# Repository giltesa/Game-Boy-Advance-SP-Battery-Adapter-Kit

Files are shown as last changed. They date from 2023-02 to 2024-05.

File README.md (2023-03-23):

# Game Boy Advance SP Battery Adapter Kit

Once your **Game Boy Advance SP battery** has gone bad, and you start to look for a replacement you will see it is impossible to find original batteries since they expire if you do not keep charged with a minimum level of charge.

Compatible batteries may be an alternative. However, some manufacturers  may lie with the real capacity or their quality is not good enough.

If you have changed the screen for a IPS screen, or the [charging port for a USB-C port](https://shop.giltesa.com/product/game-boy-advance-sp-usb-c-kit-centered/ "charging port for a USB-C port"). I am sure you will also want to replace the battery and make your GBA SP perfect. This kit helps you to install any li-ion battery, however the best option is the [603048](https://www.aliexpress.com/item/4001084877373.html? "603048") which has 900mAh, that is 300mAh more than the original!

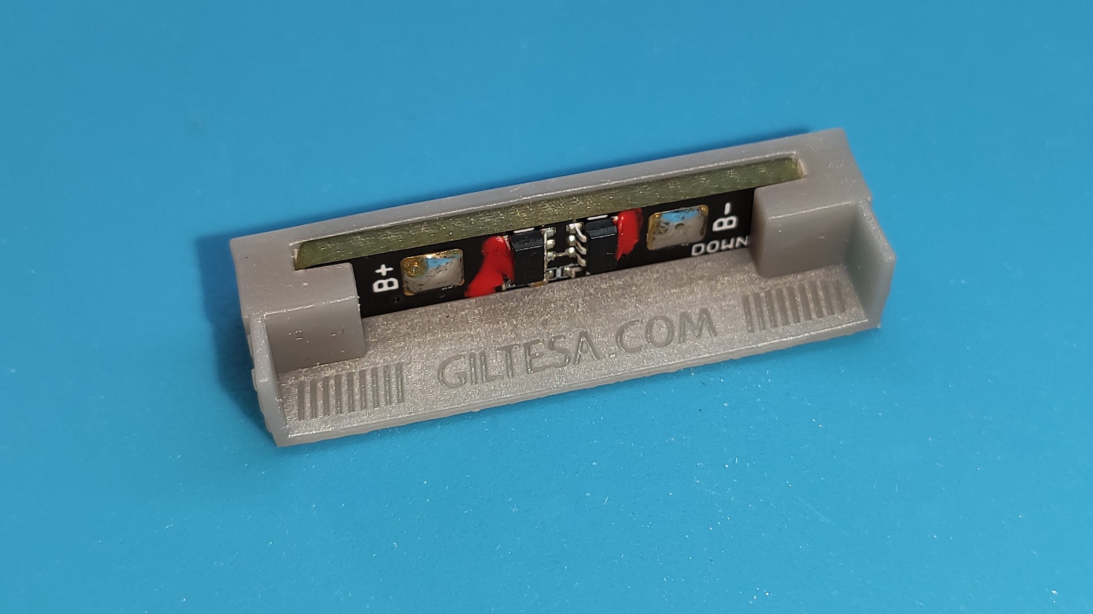
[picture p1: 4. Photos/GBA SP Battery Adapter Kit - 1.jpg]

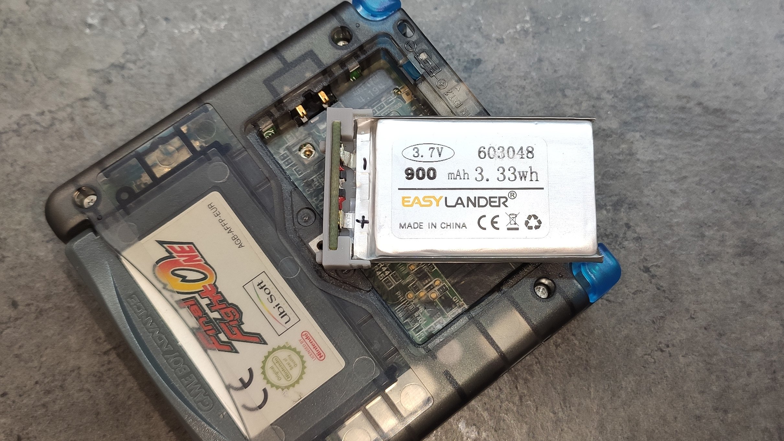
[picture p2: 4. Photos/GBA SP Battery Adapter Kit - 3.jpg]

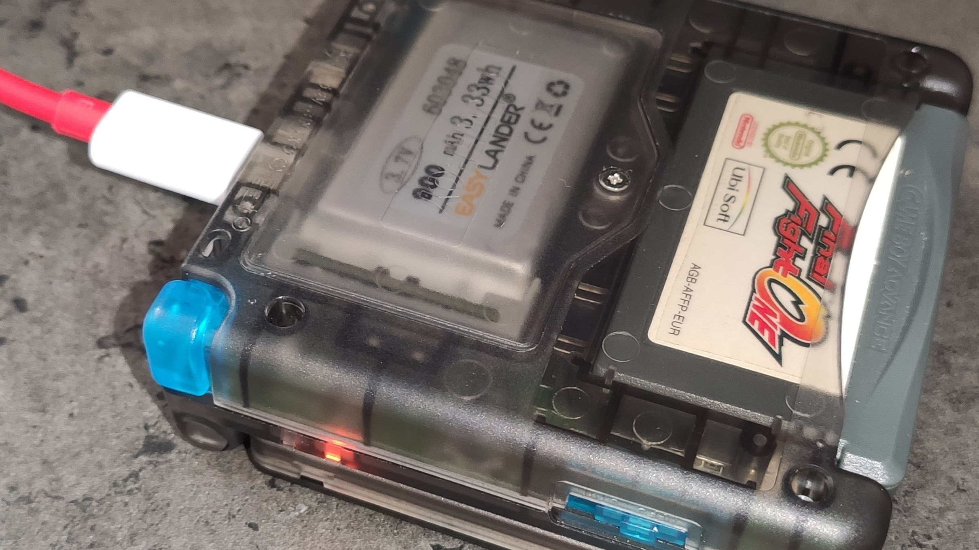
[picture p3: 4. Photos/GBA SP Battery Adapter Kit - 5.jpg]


## Would you like it?

https://shop.giltesa.com/product/game-boy-advance-sp-battery-adapter-kit

## More

- [giltesa.com](https://giltesa.com "giltesa.com")
- [twitter.com](https://twitter.com/giltesa/status/1503669454852481024 "twitter.com")

## License

This project is licensed under a **Creative Commons** license:
**[Attribution-NonCommercial-ShareAlike 4.0 International (CC BY-NC-SA 4.0) ](https://creativecommons.org/licenses/by-nc-sa/4.0/)**

Check the [LICENSE.md](LICENSE.md) for more information.

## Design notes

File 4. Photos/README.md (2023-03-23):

GBASP-BAT
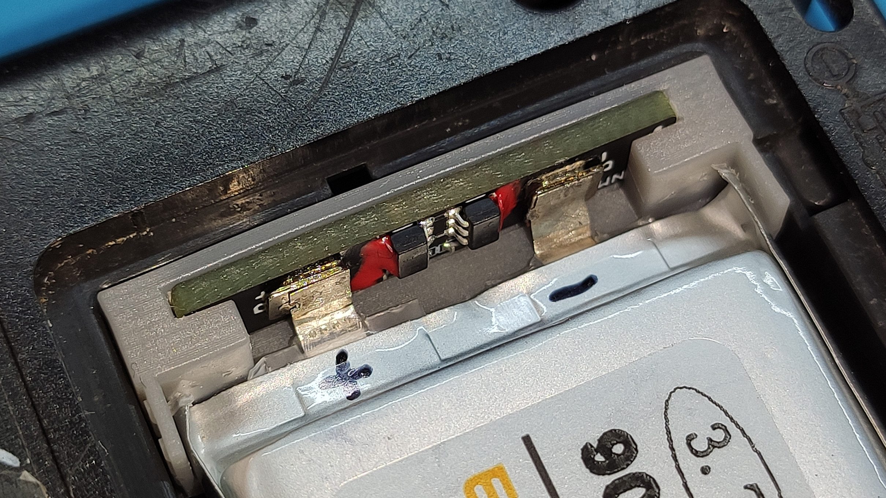
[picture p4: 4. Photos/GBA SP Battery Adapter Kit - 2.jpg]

GBASP-BAT
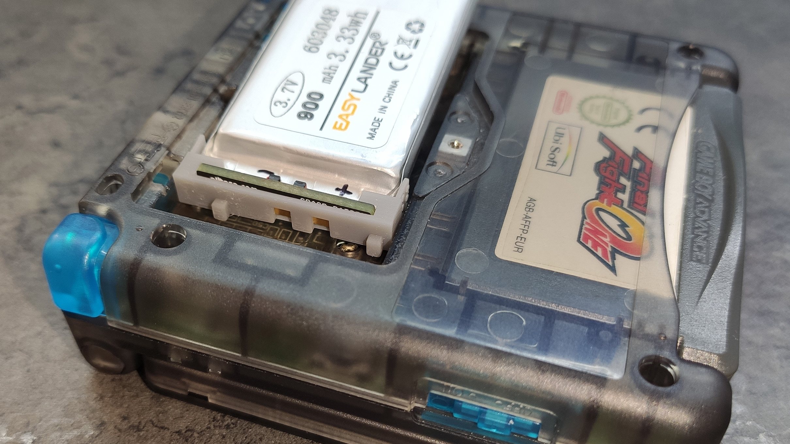
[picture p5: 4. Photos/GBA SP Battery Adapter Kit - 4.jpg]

GBASP-BAT
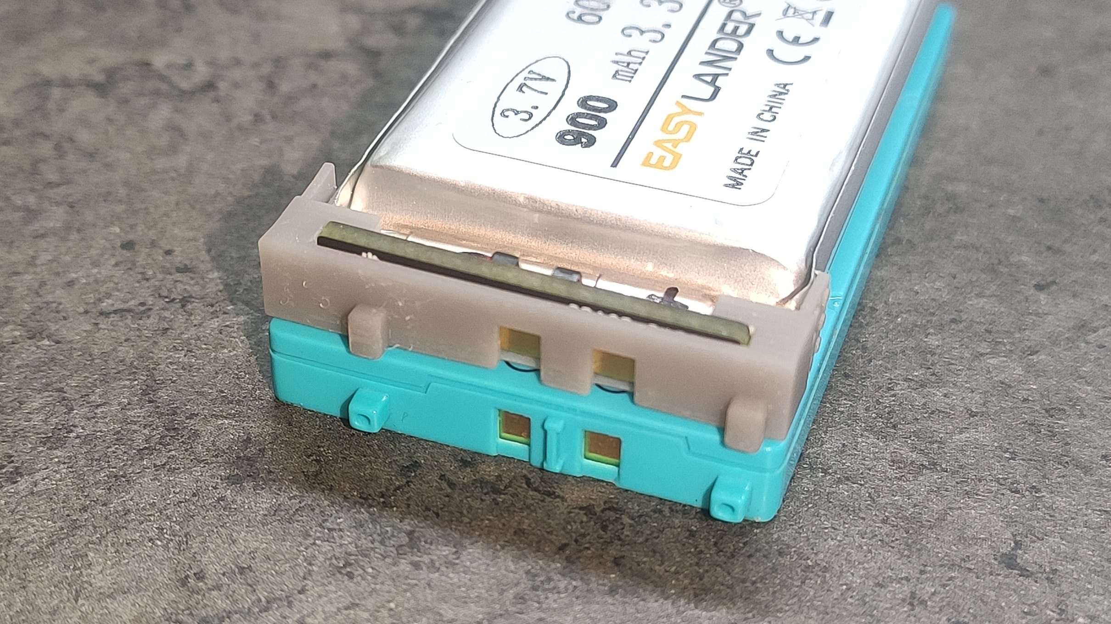
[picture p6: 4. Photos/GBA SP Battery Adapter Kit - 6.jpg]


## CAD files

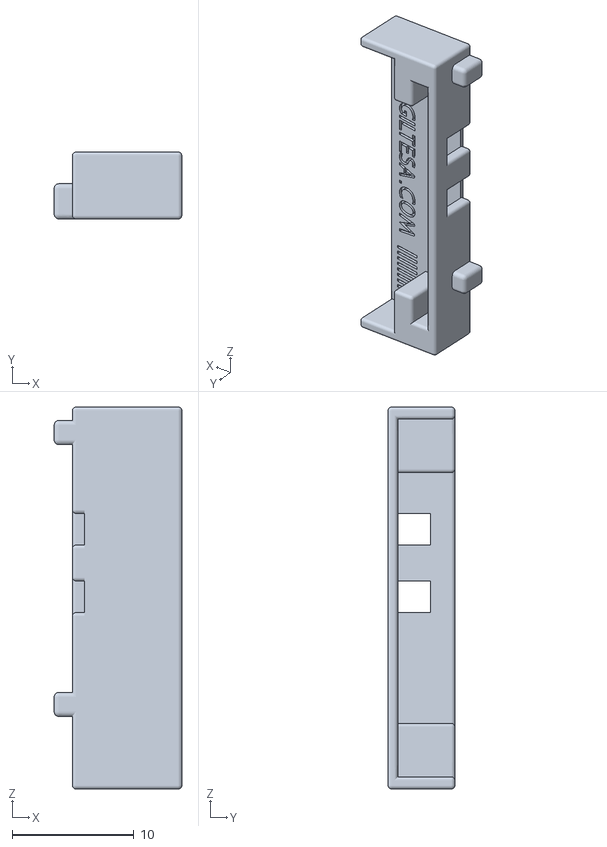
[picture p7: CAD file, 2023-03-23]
2. Renders, 3D models/Plastic Adapter/Game Boy Advance SP Battery v1.2 v8.stl
10.5 x 5.50 x 31.4

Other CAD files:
2. Renders, 3D models/battery v1.0.skp
2. Renders, 3D models/battery v1.1.skp
2. Renders, 3D models/battery v1.2_black.skp

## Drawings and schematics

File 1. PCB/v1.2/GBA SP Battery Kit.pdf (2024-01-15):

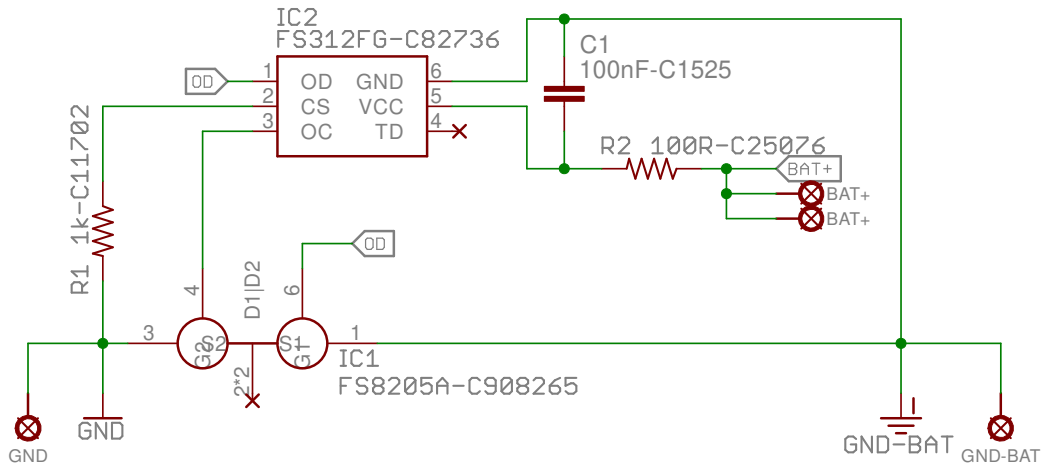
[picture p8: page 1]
BAT+; GND; GND-BAT; 4 VCC; 5 GND

GBA SP BATTERY ADAPTER KIT
https://giltesa.com

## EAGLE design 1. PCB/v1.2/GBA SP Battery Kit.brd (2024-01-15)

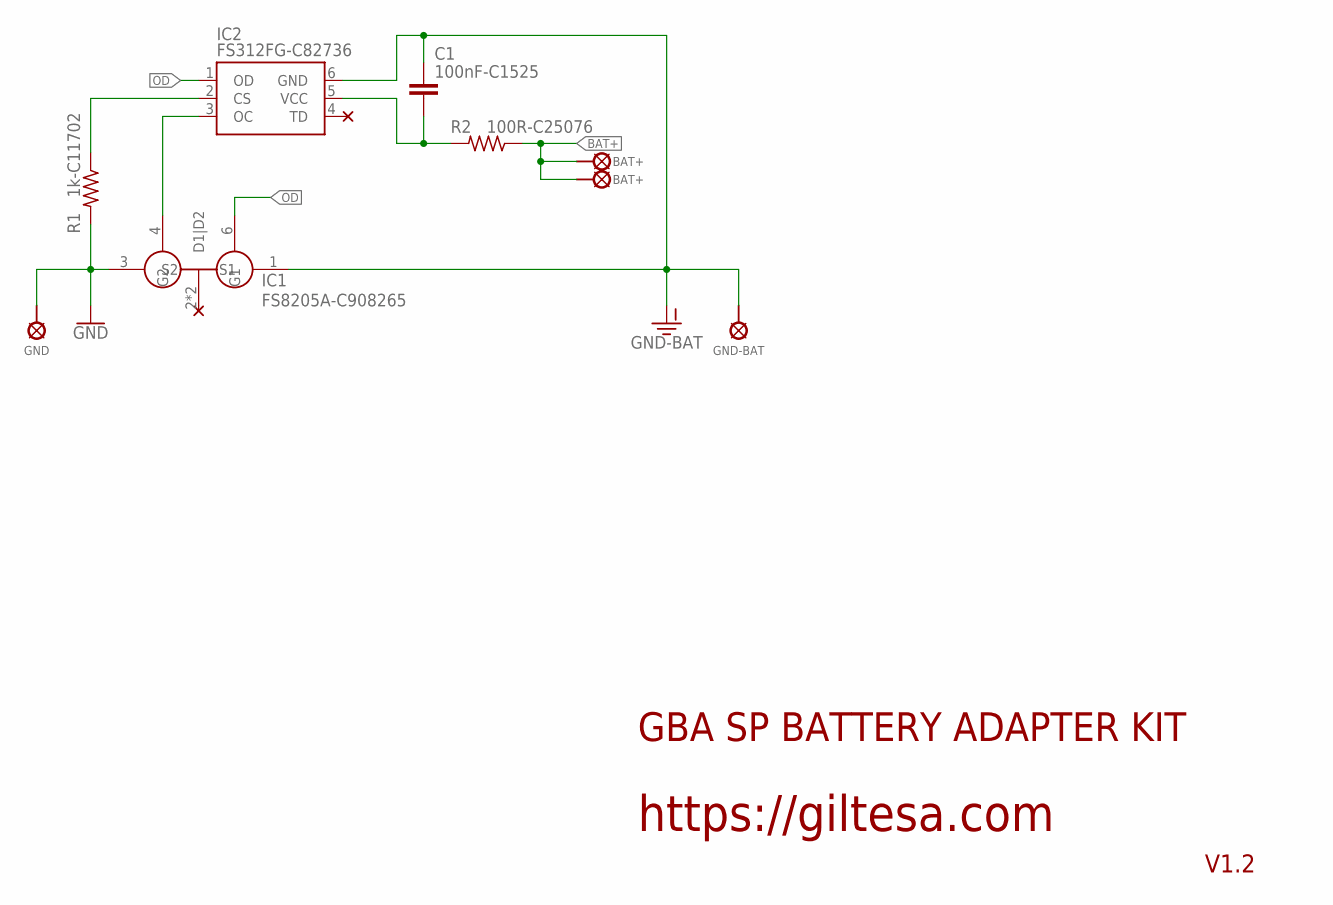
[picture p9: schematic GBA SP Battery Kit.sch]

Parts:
C1: 100nF-C1525; C0402_S
IC1: FS8205A-C908265; SOT-23-6_GBASP
IC2: FS312FG-C82736; SOT-23-6_GBASP_SHORT
R1: 1k-C11702; R0402
R2: 100R-C25076; R0402
U$2: BAT+; BATTERY_SOLDER_PAD
U$4: GND-BAT; BATTERY_SOLDER_PAD
U$5: GND; BATTERY_SOLDER_PAD_GBASP
U$9: BAT+; BATTERY_SOLDER_PAD_GBASP

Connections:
BAT+: R2.1, U$2.1, U$9.1
GND: IC1.3 (S2), R1.2, U$5.1
GND-BAT: C1.1, IC1.1 (S1), IC2.6 (GND), U$4.1
unnamed: IC2.2 (CS), R1.1
unnamed: IC1.4 (G2), IC2.3 (OC)
OD: IC1.6 (G1), IC2.1 (OD)
VCC-DW: C1.2, IC2.5 (VCC), R2.2

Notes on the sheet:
https://giltesa.com
V1.2
GBA SP BATTERY ADAPTER KIT

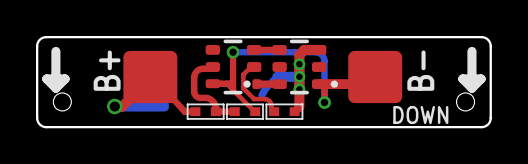
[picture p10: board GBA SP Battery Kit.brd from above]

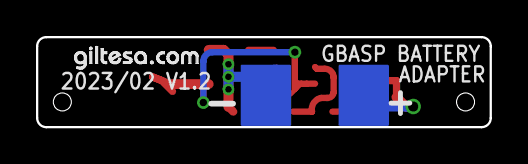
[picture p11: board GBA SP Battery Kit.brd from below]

Board: 2 copper layers, 25.2 x 5.0 mm, 10 parts (3 on the bottom side), 7 nets.

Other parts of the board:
U$28: GILTESA.COM_MASK_7MM

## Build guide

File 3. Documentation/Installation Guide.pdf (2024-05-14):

# Battery ADAPTER Kit for GAME BOY Advance SP

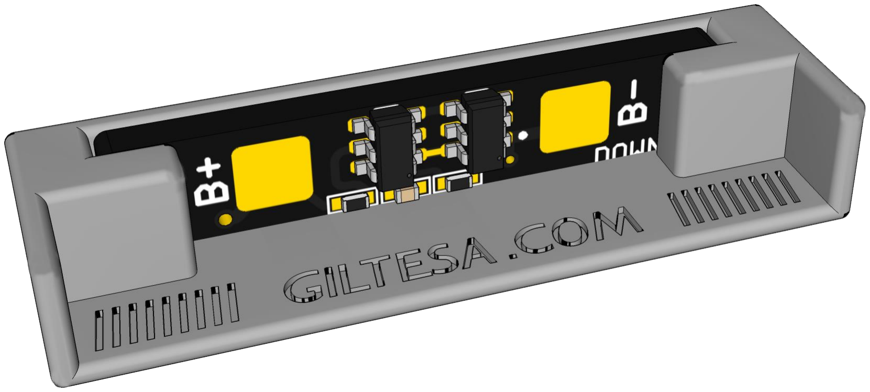
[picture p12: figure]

PRODUCT
https://shop.giltesa.com/product/game-boy-advance-sp-battery-adapter-kit

# PLEASE READ THROUGH THESE INSTRUCTIONS

ENTIRELY BEFORE ATTEMPTING TO INSTALL.

# WARNING: IF YOU ARE NOT COMFORTABLE WITH SOLDERING, OR PERFORMING ANY STEP IN THIS

GUIDE, DO NOT PERFORM THE INSTALL YOURSELF.

# FIND SOMEONE WHO IS COMFORTABLE TO DO IT FOR

YOU.

INDEX

# Description

Once your Game Boy Advance SP battery has gone bad, and you start to look for a replacement you will see it’s impossible to find original batteries since they expire if you don’t keep charged with a minimum level of charge.

Compatible batteries may be an alternative. However, some manufacturers may lie with the real capacity, or their quality is not good enough.

If you have changed the screen for a IPS screen, or the charging port for a USB-C port. (https://shop.giltesa.com/product/game-boy-advance-sp-usb-c-kit-centered/) I’m sure you will also want to replace the battery and make your GBA SP perfect. This kit helps you to install any li-ion battery, however the best option is the 603048 (https://www.aliexpress.com/item/4001084877373.html) which has 900mAh, that is 300mAh more than the original!

# FEATURES

- Exact shape for Game Boy Advance SP.
- Protection circuit of over-discharge.

# INCLUDED

- 1 board.
- 1 Plastic adapter.

# Recommended / REQUIRED (NOT INCLUDED)

- Li-ion battery, recommended this one: 603048 (https://www.aliexpress.com/item/4001084877373.html) of 900mAh.
- Phillips screwdriver
- Tri-wing screwdriver (optional)
- Soldering iron
- Tin
- Flux

# Board details

The following explains what each pad is for.

- B+ | The positive input from the li-ion battery.
- B- | The negative input from the li-ion battery.
- + | The positive output to the GBA SP.
- - | The negative output to the GBA SP.

# INSTALLATION STEPS

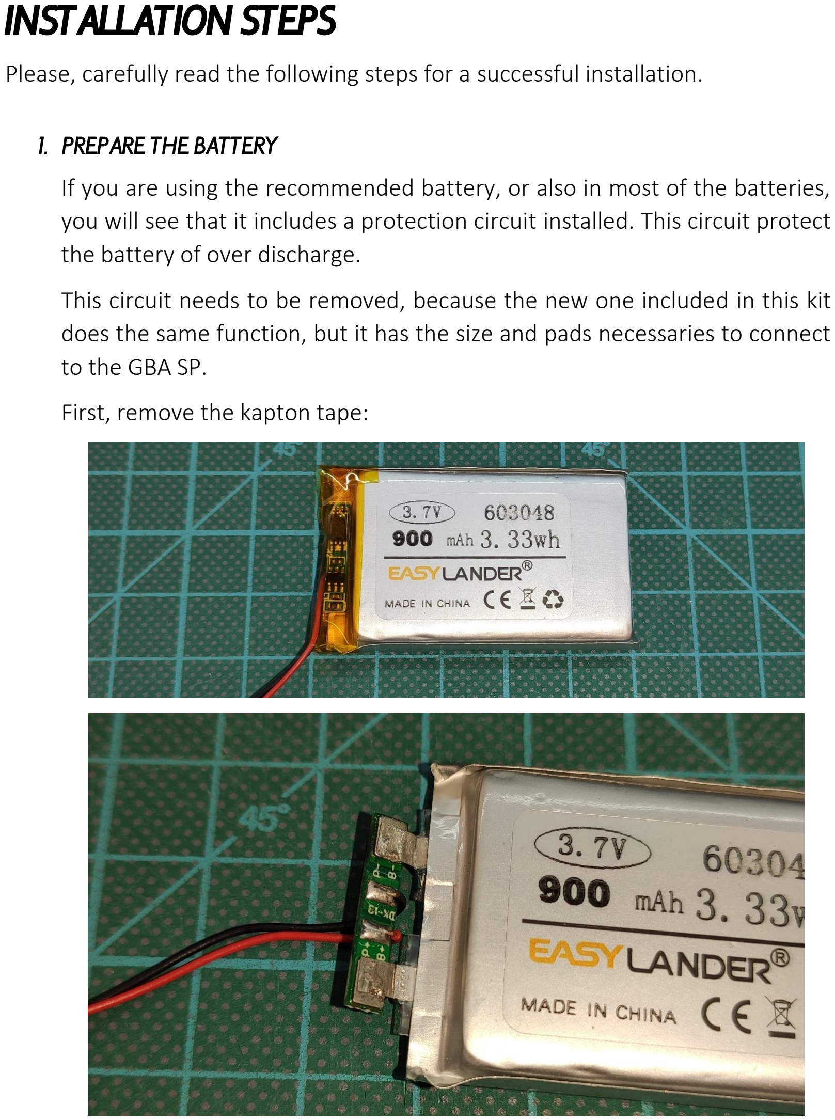
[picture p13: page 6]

Please, carefully read the following steps for a successful installation.

1. Prepare the battery

If you are using the recommended battery, or also in most of the batteries, you will see that it includes a protection circuit installed. This circuit protect the battery of over discharge.

This circuit needs to be removed, because the new one included in this kit does the same function, but it has the size and pads necessaries to connect to the GBA SP.

First, remove the kapton tape:

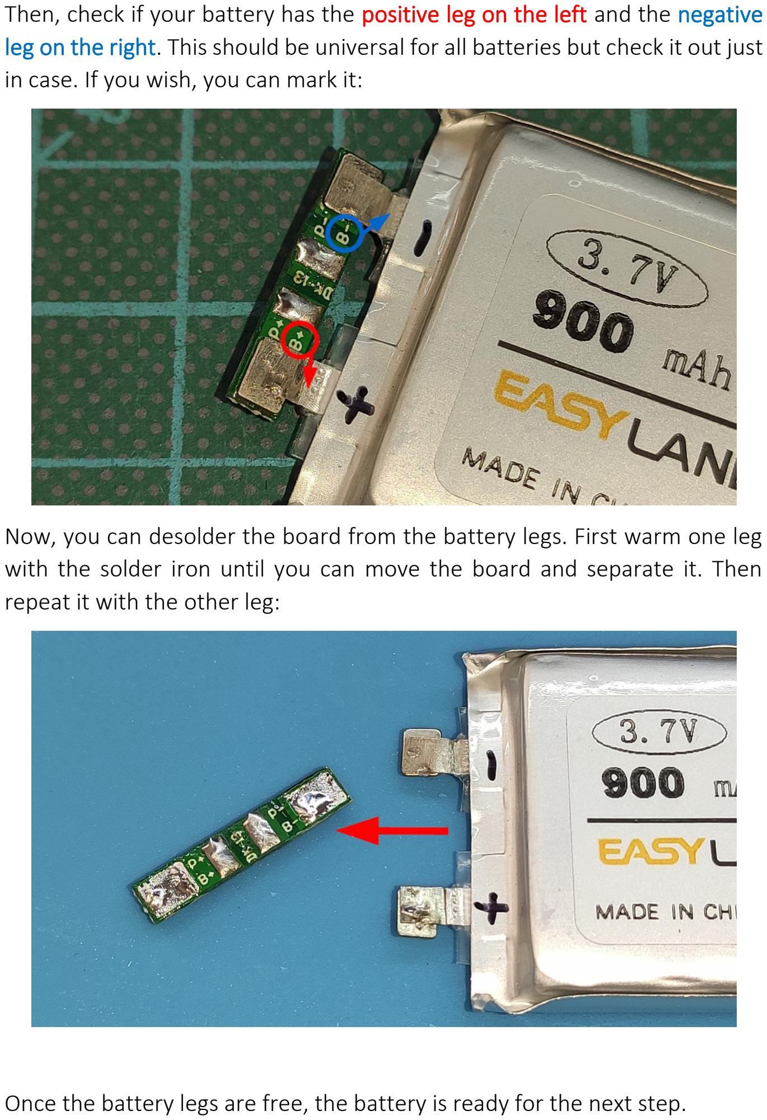
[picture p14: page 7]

Then, check if your battery has the positive leg on the left and the negative leg on the right. This should be universal for all batteries but check it out just in case. If you wish, you can mark it:

Now, you can desolder the board from the battery legs. First warm one leg with the solder iron until you can move the board and separate it. Then repeat it with the other leg:

Once the battery legs are free, the battery is ready for the next step.

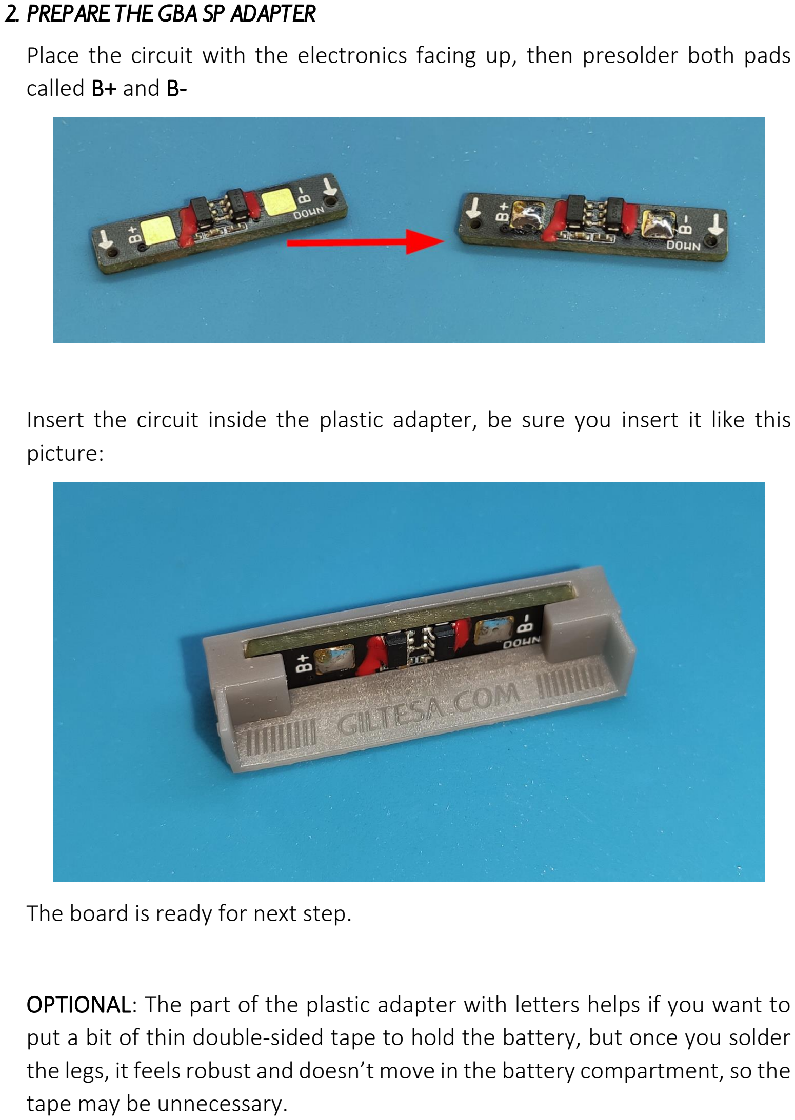
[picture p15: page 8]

2. Prepare the GBA SP adapter

Place the circuit with the electronics facing up, then presolder both pads called B+ and B-

Insert the circuit inside the plastic adapter, be sure you insert it like this picture:

The board is ready for next step.

OPTIONAL: The part of the plastic adapter with letters helps if you want to put a bit of thin double-sided tape to hold the battery, but once you solder the legs, it feels robust and doesn’t move in the battery compartment, so the tape may be unnecessary.

3. Solder the battery to the board adapter

The distance between the battery and the adapter must be the correct one, otherwise the assembled battery may not fit in the battery compartment or may not touch the GBA SP pads and do bad electric connection.

The easiest way to assemble it well, it’s doing inside the battery compartment. However, the GBA SP spring contacts may annoy you when you put the adapter in the place.

If you have other GBA SP shell not assembled, or you can remove the bottom shell, it will help:

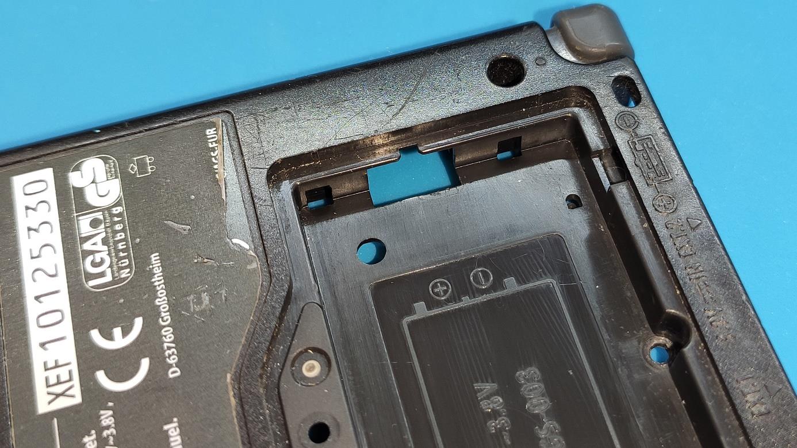
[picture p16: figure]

First, put the adapter in position:

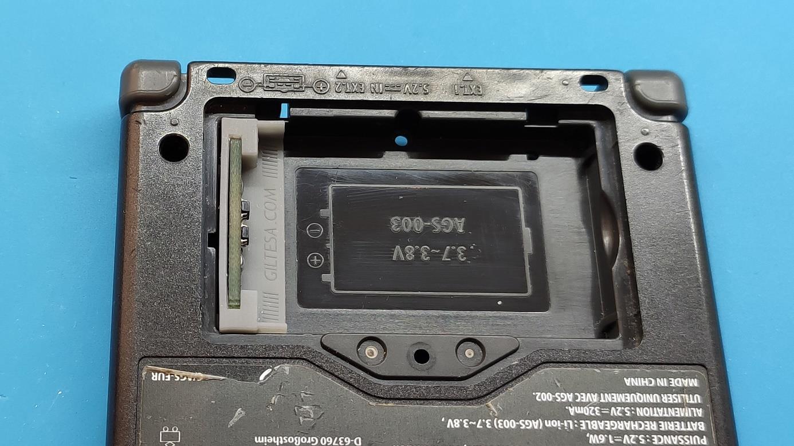
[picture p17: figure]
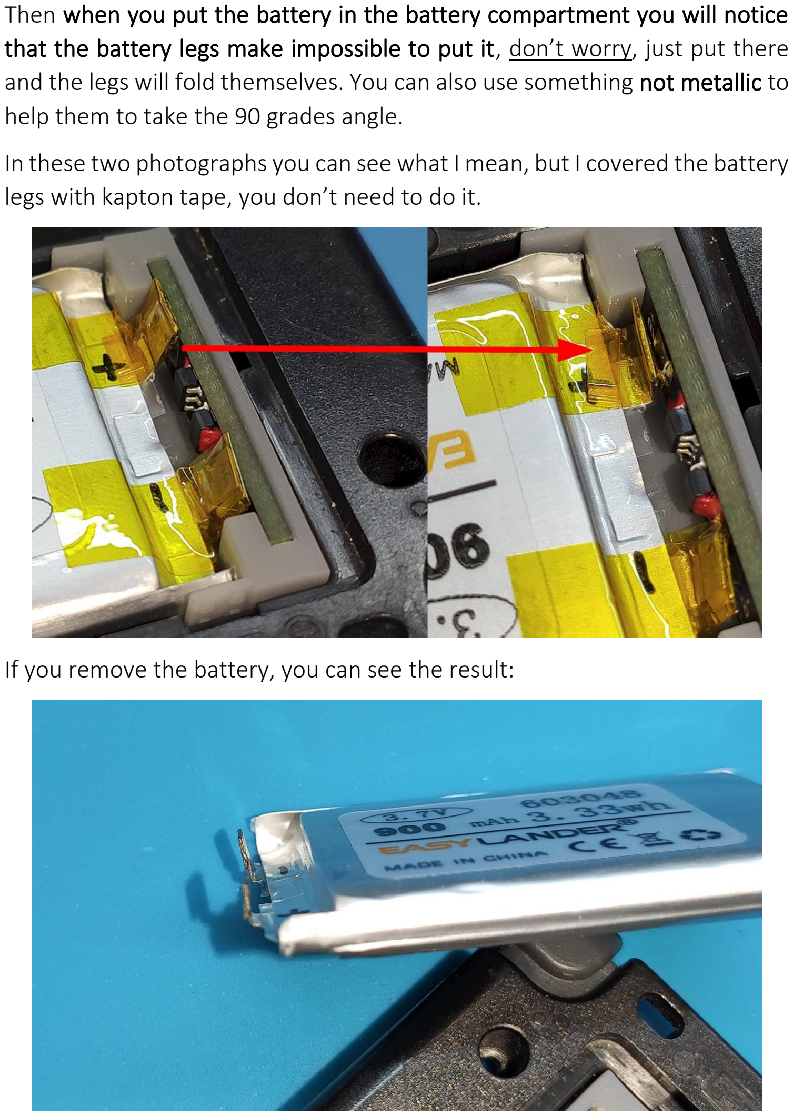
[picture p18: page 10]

Then when you put the battery in the battery compartment you will notice that the battery legs make impossible to put it, don’t worry, just put there and the legs will fold themselves. You can also use something not metallic to help them to take the 90 grades angle.

In these two photographs you can see what I mean, but I covered the battery legs with kapton tape, you don’t need to do it.

If you remove the battery, you can see the result:

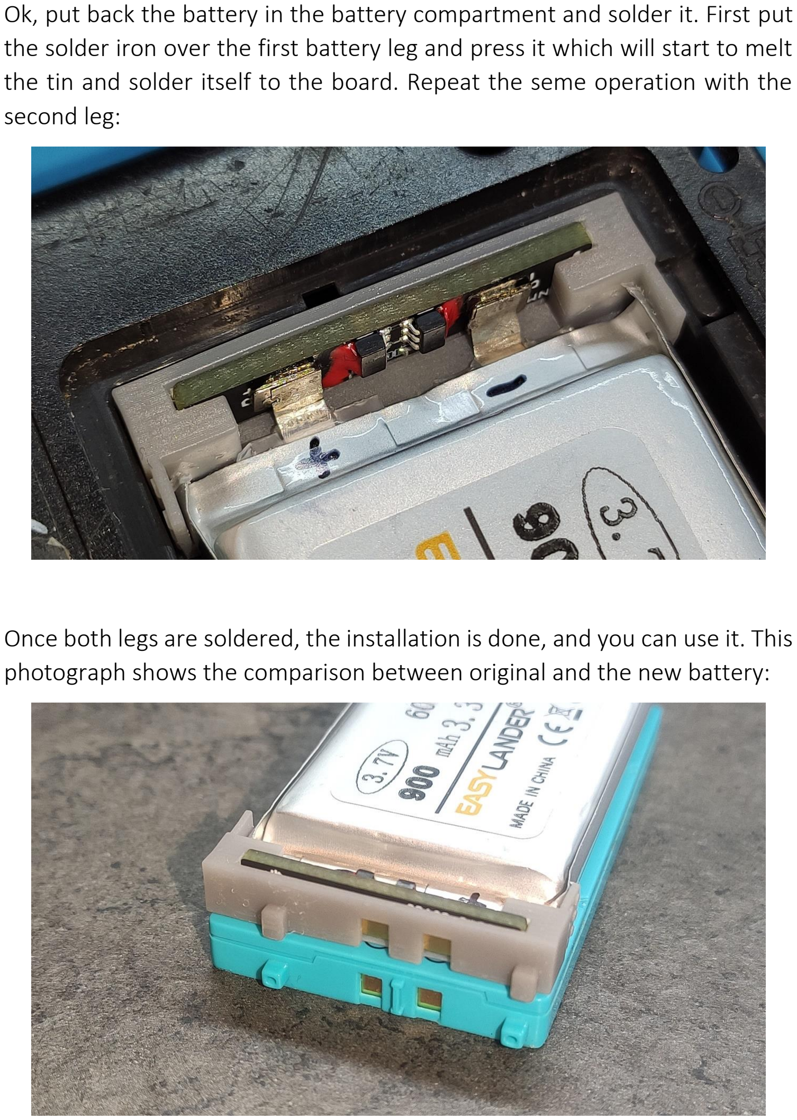
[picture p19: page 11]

Ok, put back the battery in the battery compartment and solder it. First put the solder iron over the first battery leg and press it which will start to melt the tin and solder itself to the board. Repeat the seme operation with the second leg:

Once both legs are soldered, the installation is done, and you can use it. This photograph shows the comparison between original and the new battery:

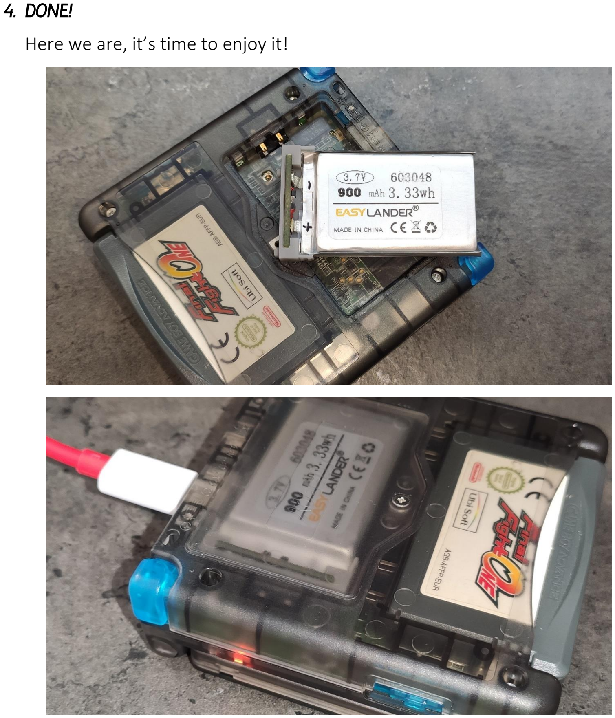
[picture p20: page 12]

4. Done!

Here we are, it’s time to enjoy it!

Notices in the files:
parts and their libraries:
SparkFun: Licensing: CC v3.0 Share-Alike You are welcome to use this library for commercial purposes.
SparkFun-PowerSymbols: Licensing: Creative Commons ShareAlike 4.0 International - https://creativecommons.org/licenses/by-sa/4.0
